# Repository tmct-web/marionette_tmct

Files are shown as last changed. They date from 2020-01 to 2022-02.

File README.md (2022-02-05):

# marionette_tmct

## What is "Marionette" ?
Marionettes are so-called puppets.We created this to remotely control multiple remote devices via USB from a single PC.

This system contains two Arduino Leonardo, the controlling side (master side) and the controlled side (slave side).

For example, the USB port connected to the controlling side (master side) is USB-COM, and the USB port connected to the controlled side (slave side) is an HID keyboard (= the slave side looks like a normal HID keyboard). Then you can control the slave keyboard with USB-COM on the master.

マリオネッテと書いてマリオネットと読みます。マリオネットはいわゆる操り人形のことですね。
もともと1台のパソコンからUSB経由で複数の相手機器を遠隔コントロールするために作ったものです。

このシステムは、制御する側（マスタ側）・制御される側（スレーブ側）の2つ分のArduino Leonardoが入っている、ちょっと変わったハードウェアになっています。

たとえば制御する側（マスタ側）に繋がるUSBポートはUSB-COM、制御される側（スレーブ側）につながるUSBポートはHIDキーボード（＝スレーブ側は普通のHIDキーボードに見える）、という構成にすると、マスタ側のUSB-COMでスレーブ側をキーボード制御する、なんてことができます。

Example

## Hardware specifications
Marionette has two circuits of Arduino Leonardo.

The two circuits are called a master (MASTER) and a slave (SLAVE), respectively, and can be operated completely differently by different programs. The hardware block diagram is shown below.

MarionetteはArduino Leonardoの2枚分の回路が実装されています。

2枚分の回路はそれぞれマスタ(MASTER)とスレーブ(SLAVE)と呼び、各々別のプログラムでまったく別の動作をさせることができます。ハードウェアのブロック図を以下に示します。

Hardware block diagram

See our [homepage](https://ss1.xrea.com/tmct.s1009.xrea.com/work/td-ja-7e2g01.html) for more information.(* Japanese only)

詳細は [ホームページ](https://ss1.xrea.com/tmct.s1009.xrea.com/work/td-ja-7e2g01.html) を参照してください。

## Recommended projects
We recommend this project. Compatibility with Marionette is outstanding.

Marionetteで使用すると、良い結果が得られるでしょう。

[NicoHood/HID](https://github.com/NicoHood/HID)

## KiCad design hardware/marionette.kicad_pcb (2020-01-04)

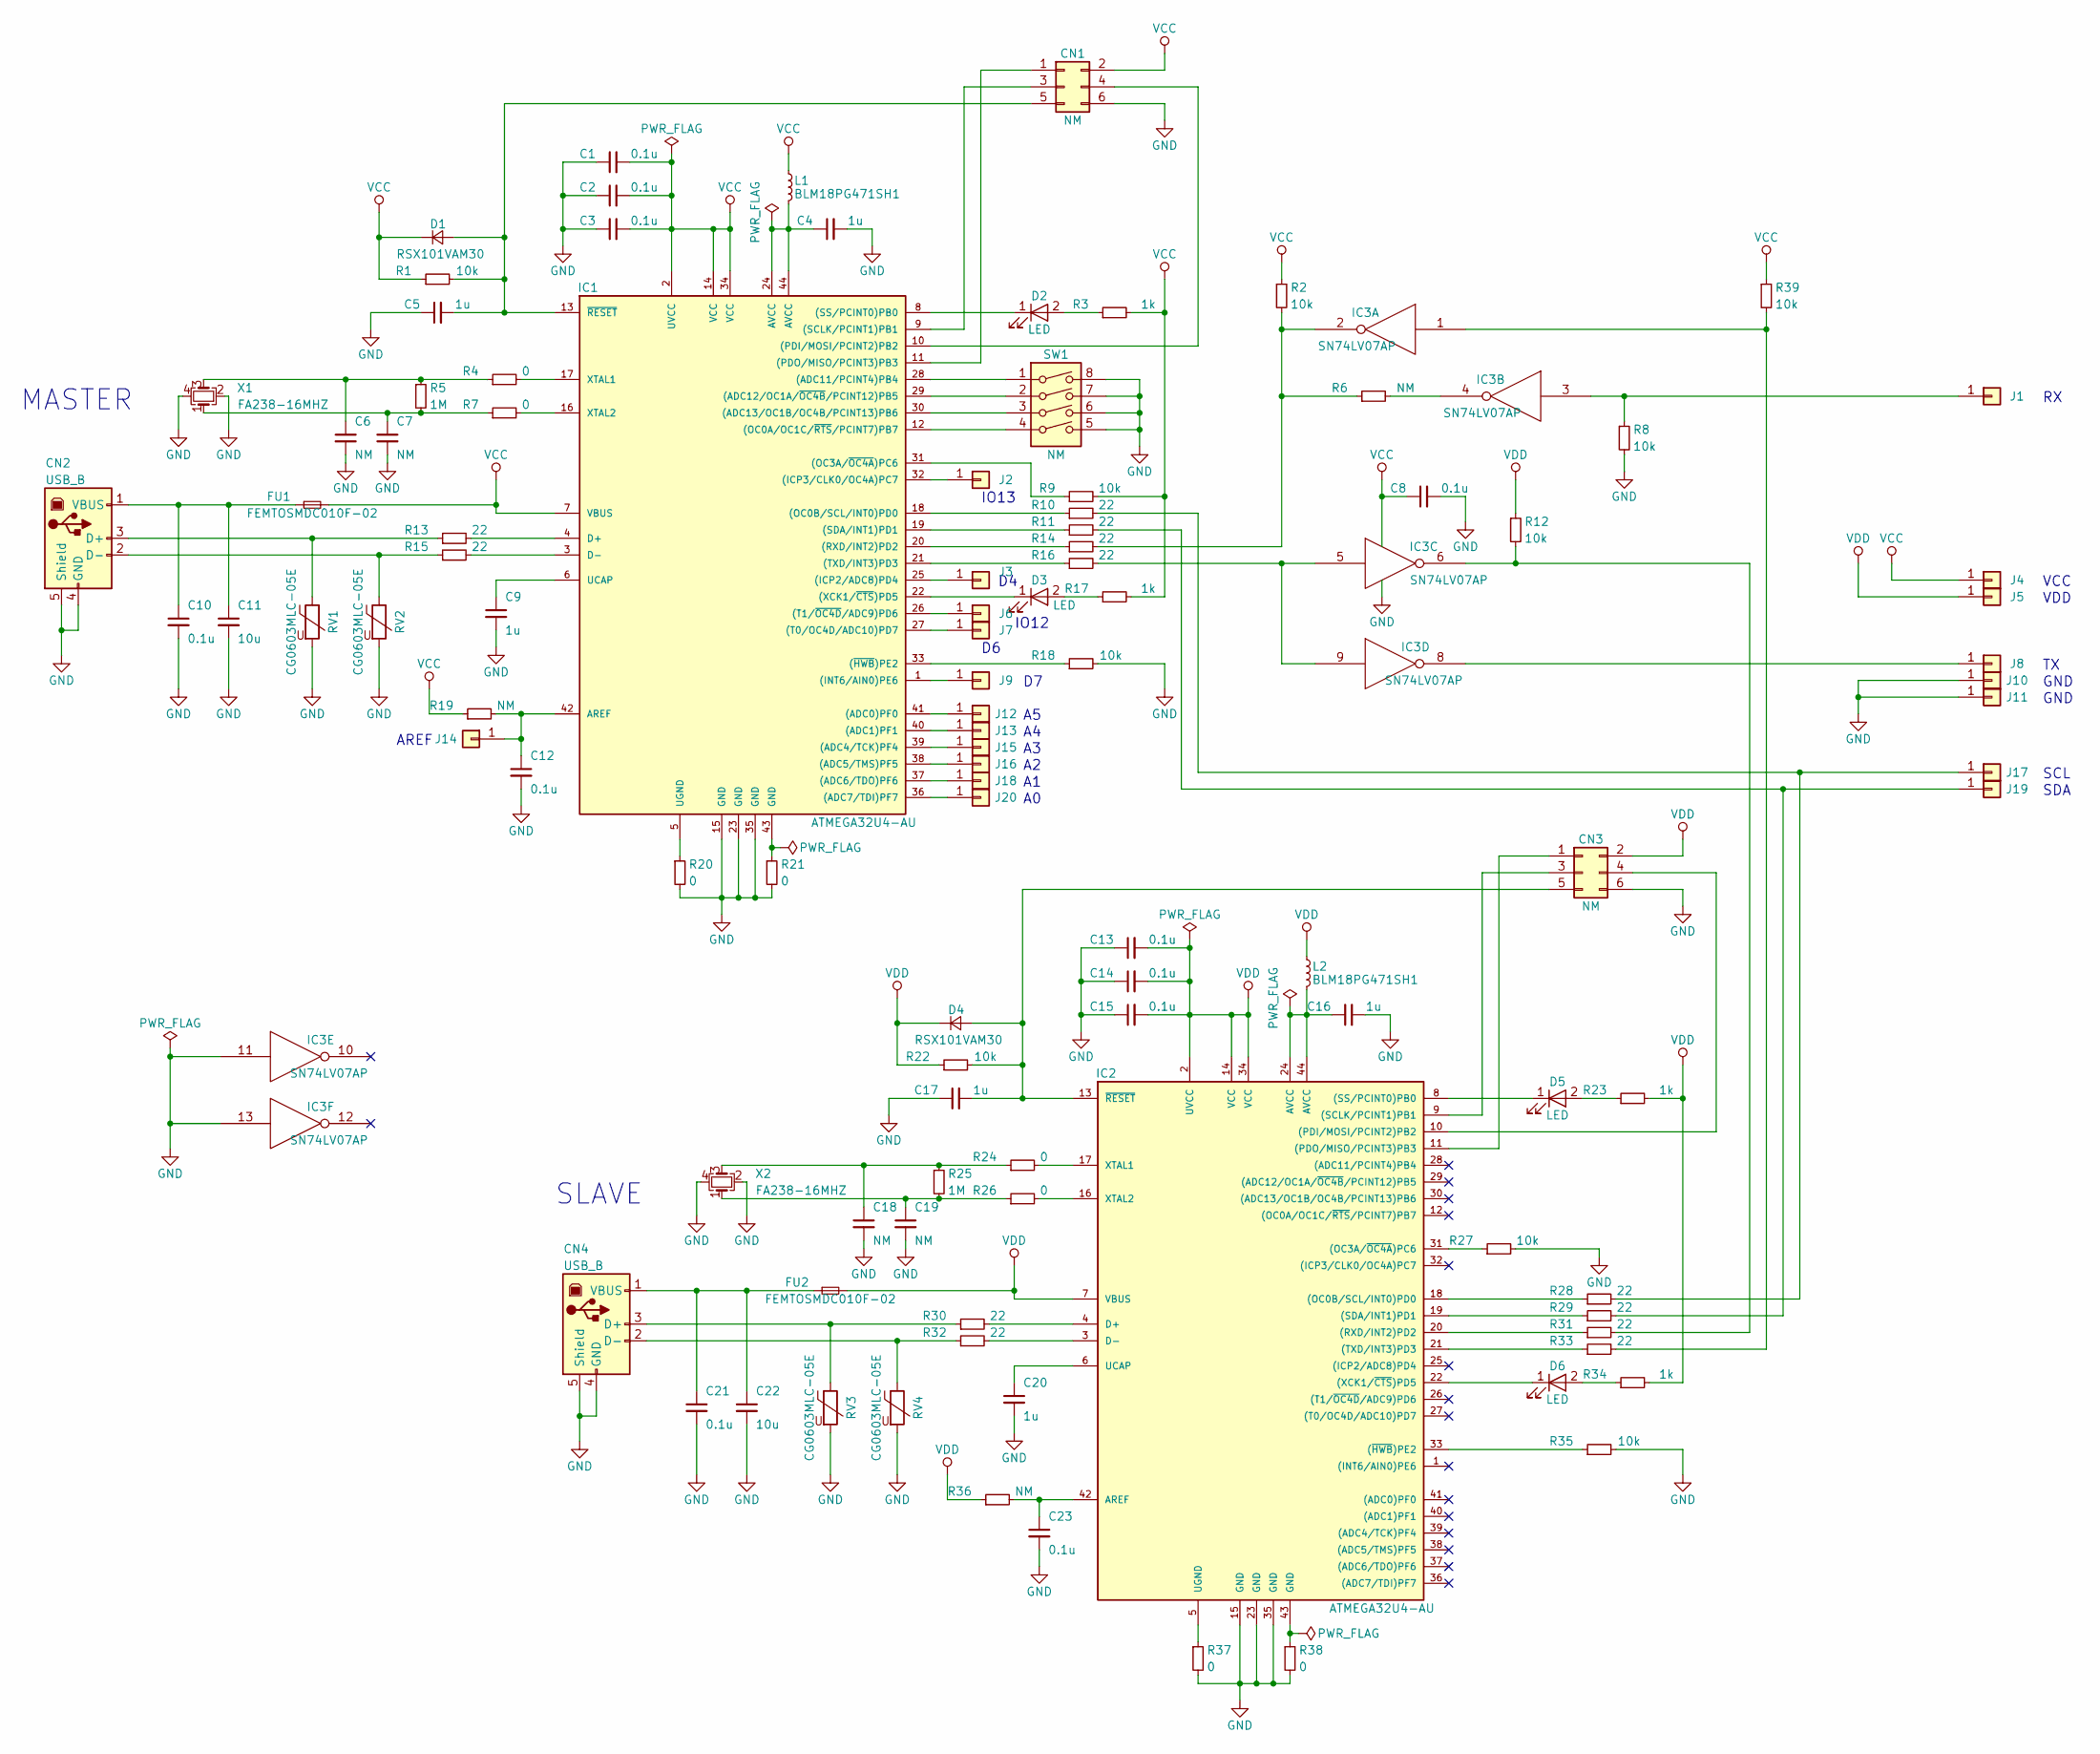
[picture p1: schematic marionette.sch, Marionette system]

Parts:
C1, C2, C3, C8, C10, C12, C13, C14, C15, C21, C23: 0.1u; C_0603
C4, C5, C9, C16, C17, C20: 1u; C_0603
C6, C7, C18, C19: NM; C_0603
C11, C22: 10u; C_0805
CN1, CN3: NM; Pin_Header_Straight_2x03_Pitch2.54mm
CN2, CN4: USB_B
D1, D4: RSX101VAM30; D_TUMD2
D2, D3, D5, D6: LED; LED_0603
FU1, FU2: FEMTOSMDC010F-02; C_0603
IC1, IC2: ATMEGA32U4-AU; TQFP-44_10x10mm_Pitch0.8mm
IC3: SN74LV07AP; TSSOP-14_4.4x5mm_Pitch0.65mm
J1, J2, J3, J4, J5, J6, J7, J8, J9, J10, J11, J12, J13, J14, J15, J16, J17, J18, J19, J20: Conn_01x01; Measurement_Point_Round-TH_Small
L1, L2: BLM18PG471SH1; L_0603
R1, R2, R8, R9, R12, R18, R22, R27, R35, R39: 10k; R_0603
R3, R17, R23, R34: 1k; R_0603
R4, R7, R20, R21, R24, R26, R37, R38: 0; R_0603
R5, R25: 1M; R_0603
R6, R19, R36: NM; R_0603
R10, R11, R13, R14, R15, R16, R28, R29, R30, R31, R32, R33: 22; R_0603
RV1, RV2, RV3, RV4: CG0603MLC-05E; C_0603
SW1: NM; DIP-8_W7.62mm_LongPads
X1, X2: FA238-16MHZ; Crystal_SMD_3225-4pin_3.2x2.5mm

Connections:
GND: C1.1, C2.1, C3.1, C4.2, C5.1, C6.2, C7.2, C8.2, C9.2, C10.2, C11.2, C12.2, C13.1, C14.1, C15.1, C16.2, C17.1, C18.2, C19.2, C20.2, C21.2, C22.2, C23.2, CN1.6, CN2.4 (GND), CN2.5 (Shield), CN3.6, CN4.4 (GND), CN4.5 (Shield), IC1.15 (GND), IC1.23 (GND), IC1.35 (GND), IC2.15 (GND), IC2.23 (GND), IC2.35 (GND), IC3.7 (GND), IC3.11, IC3.13, J10.1, J11.1, R8.2, R18.2, R20.2, R21.2, R27.2, R35.2, R37.2, R38.2, RV1.2, RV2.2, RV3.2, RV4.2, SW1.5, SW1.6, SW1.7, SW1.8, X1.2, X1.4, X2.2, X2.4
unnamed: C4.1, IC1.24 (AVCC), IC1.44 (AVCC), L1.2
unnamed: C5.2, CN1.5, D1.2 (A), IC1.13 (~RESET~), R1.2
unnamed: C6.1, R4.1, R5.1, X1.3
unnamed: C7.1, R5.2, R7.1, X1.1
unnamed: C9.1, IC1.6 (UCAP)
unnamed: C10.1, C11.1, CN2.1 (VBUS), FU1.1
unnamed: C12.1, IC1.42 (AREF), J14.1, R19.2
unnamed: C16.1, IC2.24 (AVCC), IC2.44 (AVCC), L2.2
unnamed: C17.2, CN3.5, D4.2 (A), IC2.13 (~RESET~), R22.2
unnamed: C18.1, R24.1, R25.1, X2.3
unnamed: C19.1, R25.2, R26.1, X2.1
unnamed: C20.1, IC2.6 (UCAP)
unnamed: C21.1, C22.1, CN4.1 (VBUS), FU2.1
unnamed: C23.1, IC2.42 (AREF), R36.2
unnamed: CN1.1, IC1.11 ((PDO/MISO/PCINT3)PB3)
unnamed: CN1.3, IC1.9 ((SCLK/PCINT1)PB1)
unnamed: CN1.4, IC1.10 ((PDI/MOSI/PCINT2)PB2)
unnamed: CN2.2 (D-), R15.1, RV2.1
unnamed: CN2.3 (D+), R13.1, RV1.1
unnamed: CN3.1, IC2.11 ((PDO/MISO/PCINT3)PB3)
unnamed: CN3.3, IC2.9 ((SCLK/PCINT1)PB1)
unnamed: CN3.4, IC2.10 ((PDI/MOSI/PCINT2)PB2)
unnamed: CN4.2 (D-), R32.1, RV4.1
unnamed: CN4.3 (D+), R30.1, RV3.1
unnamed: D2.1 (K), IC1.8 ((SS/PCINT0)PB0)
unnamed: D2.2 (A), R3.1
unnamed: D3.1 (K), IC1.22 ((XCK1/~CTS~)PD5)
unnamed: D3.2 (A), R17.1
unnamed: D5.1 (K), IC2.8 ((SS/PCINT0)PB0)
unnamed: D5.2 (A), R23.1
unnamed: D6.1 (K), IC2.22 ((XCK1/~CTS~)PD5)
unnamed: D6.2 (A), R34.1
unnamed: IC1.1 ((INT6/AIN0)PE6), J9.1
unnamed: IC1.3 (D-), R15.2
unnamed: IC1.4 (D+), R13.2
unnamed: IC1.5 (UGND), R20.1
unnamed: IC1.12 ((OC0A/OC1C/~RTS~/PCINT7)PB7), SW1.4
unnamed: IC1.16 (XTAL2), R7.2
unnamed: IC1.17 (XTAL1), R4.2
unnamed: IC1.18 ((OC0B/SCL/INT0)PD0), R10.1
unnamed: IC1.19 ((SDA/INT1)PD1), R11.1
unnamed: IC1.20 ((RXD/INT2)PD2), R14.1
unnamed: IC1.21 ((TXD/INT3)PD3), R16.1
unnamed: IC1.25 ((ICP2/ADC8)PD4), J3.1
unnamed: IC1.26 ((T1/~OC4D~/ADC9)PD6), J6.1
unnamed: IC1.27 ((T0/OC4D/ADC10)PD7), J7.1
unnamed: IC1.28 ((ADC11/PCINT4)PB4), SW1.1
unnamed: IC1.29 ((ADC12/OC1A/~OC4B~/PCINT12)PB5), SW1.2
unnamed: IC1.30 ((ADC13/OC1B/OC4B/PCINT13)PB6), SW1.3
unnamed: IC1.31 ((OC3A/~OC4A~)PC6), R9.1
unnamed: IC1.32 ((ICP3/CLK0/OC4A)PC7), J2.1
unnamed: IC1.33 ((~HWB~)PE2), R18.1
unnamed: IC1.36 ((ADC7/TDI)PF7), J20.1
unnamed: IC1.37 ((ADC6/TDO)PF6), J18.1
unnamed: IC1.38 ((ADC5/TMS)PF5), J16.1
unnamed: IC1.39 ((ADC4/TCK)PF4), J15.1
unnamed: IC1.40 ((ADC1)PF1), J13.1
unnamed: IC1.41 ((ADC0)PF0), J12.1
unnamed: IC1.43 (GND), R21.1
unnamed: IC2.3 (D-), R32.2
unnamed: IC2.4 (D+), R30.2
unnamed: IC2.5 (UGND), R37.1
unnamed: IC2.16 (XTAL2), R26.2
unnamed: IC2.17 (XTAL1), R24.2
unnamed: IC2.18 ((OC0B/SCL/INT0)PD0), R28.1
unnamed: IC2.19 ((SDA/INT1)PD1), R29.1
unnamed: IC2.20 ((RXD/INT2)PD2), R31.1
unnamed: IC2.21 ((TXD/INT3)PD3), R33.1
unnamed: IC2.31 ((OC3A/~OC4A~)PC6), R27.1
unnamed: IC2.33 ((~HWB~)PE2), R35.1
unnamed: IC2.43 (GND), R38.1
unnamed: IC3.1, R33.2, R39.2
unnamed: IC3.2, R2.2, R6.1, R14.2
unnamed: IC3.3, J1.1, R8.1
unnamed: IC3.4, R6.2
unnamed: IC3.5, IC3.9, R16.2
unnamed: IC3.6, R12.2, R31.2
unnamed: IC3.8, J8.1
unnamed: J17.1, R10.2, R28.2
unnamed: J19.1, R11.2, R29.2
VCC: C1.2, C2.2, C3.2, C8.1, CN1.2, D1.1 (K), FU1.2, IC1.2 (UVCC), IC1.7 (VBUS), IC1.14 (VCC), IC1.34 (VCC), IC3.14 (VCC), J4.1, L1.1, R1.1, R2.1, R3.2, R9.2, R17.2, R19.1, R39.1
VDD: C13.2, C14.2, C15.2, CN3.2, D4.1 (K), FU2.2, IC2.2 (UVCC), IC2.7 (VBUS), IC2.14 (VCC), IC2.34 (VCC), J5.1, L2.1, R12.1, R22.1, R23.2, R34.2, R36.1

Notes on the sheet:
MASTER
SLAVE
AREF
VCC
VDD
GND
SCL
SDA
IO13
IO12

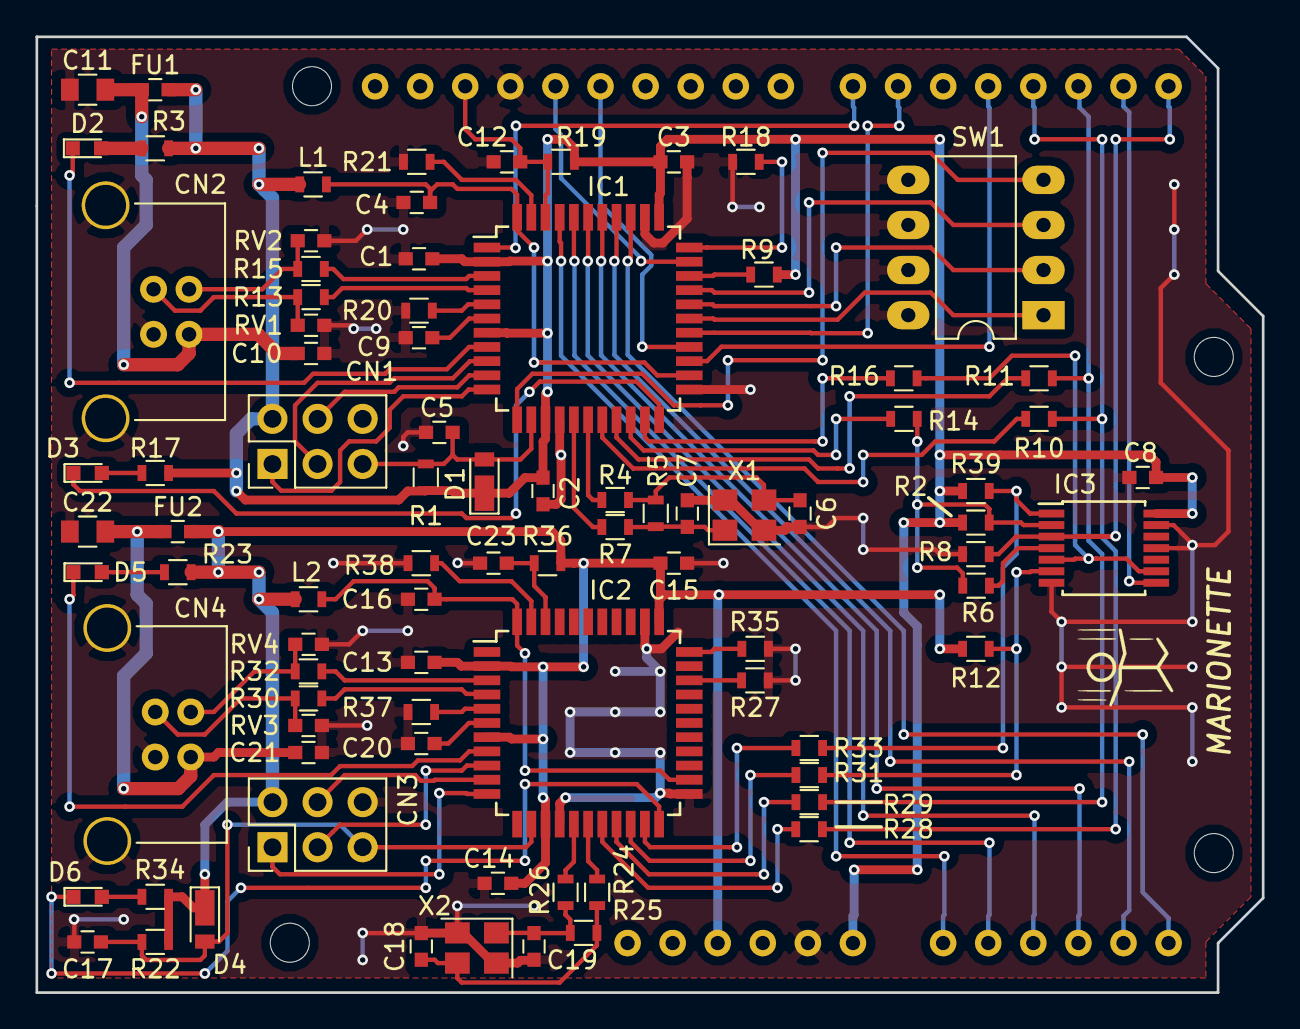
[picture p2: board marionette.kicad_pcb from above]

Board: 2 copper layers, 69.1 x 53.8 mm, 110 parts (0 on the bottom side), 83 nets.

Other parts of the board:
REF100, REF101, REF102, REF103: MountingHole_2.2mm_M2

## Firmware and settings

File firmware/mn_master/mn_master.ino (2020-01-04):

/*---------------------------------------------------------------------------*/
//  MARIONETTE system : MASTER device firmware
//
//  Filename      : mn_master.ino
//  Target system : MARIONETTE system
//  Target device : ATMEGA32U4
//
//  [Revision history]
//  Date        Version   Author            Detail
//  -------------------------------------------------------------------------
//  2018.07.15  1.00      TMC               Initial release.
/*---------------------------------------------------------------------------*/
#define receiveBufferLength 17
#define terminationCode     '\r'
#define promptCode          '$'
#define resultCode          '#'

/*---------------------------------------------------------------------------*/
//  Function prototype definition
/*---------------------------------------------------------------------------*/
void setup();
void loop();
void commandDigitalDirection();
void commandDigitalIn();
void commandDigitalOut();
void commandAnalogIn();
void commandSendToSlave();


/*---------------------------------------------------------------------------*/
//  CONST definition
/*---------------------------------------------------------------------------*/
const char messageFirmwareName[] = "MARIONETTE system firmware";
const char messageFirmwareVersion[] = "1.00";

const int portMasterDetect = 5;
const int portDipSw0 = 8;
const int portDipSw1 = 9;
const int portDipSw2 = 10;
const int portDipSw3 = 11;
const int portD3_PD0 = 3;
const int portD2_PD1 = 2;
const int portD0_PD2 = 0;
const int portD1_PD3 = 1;
const int portD4_PD4 = 4;
const int portD12_PD6 = 12;
const int portD6_PD7 = 6;
const int portD13_PC7 = 13;
const int portD7_PE6 = 7;
const int portA5_PF0 = 23;
const int portA4_PF1 = 22;
const int portA3_PF4 = 21;
const int portA2_PF5 = 20;
const int portA1_PF6 = 19;
const int portA0_PF7 = 18;


/*---------------------------------------------------------------------------*/
//  Global variable definition
/*---------------------------------------------------------------------------*/
unsigned char receiveBuffer[receiveBufferLength];
char receiveBytes;
char boardID;


/*---------------------------------------------------------------------------*/
//  Setup function
/*---------------------------------------------------------------------------*/
//  [Arguments]
//    None
//  [Returns]
//    None
//  [Note]
//    Arduino setup function
/*---------------------------------------------------------------------------*/
void setup() {
  
  /*-------------------------------------------------------------------------*/
  //  Port initialization
  /*-------------------------------------------------------------------------*/
  analogReference(DEFAULT);
  pinMode(portMasterDetect, INPUT_PULLUP);
  pinMode(portDipSw0, INPUT_PULLUP);
  pinMode(portDipSw1, INPUT_PULLUP);
  pinMode(portDipSw2, INPUT_PULLUP);
  pinMode(portDipSw3, INPUT_PULLUP);
  pinMode(portD3_PD0, INPUT_PULLUP);
  pinMode(portD2_PD1, INPUT_PULLUP);
  pinMode(portD0_PD2, INPUT_PULLUP);
  pinMode(portD1_PD3, INPUT_PULLUP);
  pinMode(portD4_PD4, INPUT_PULLUP);
  pinMode(portD12_PD6, INPUT_PULLUP);
  pinMode(portD6_PD7, INPUT_PULLUP);
  pinMode(portD13_PC7, INPUT_PULLUP);
  pinMode(portD7_PE6, INPUT_PULLUP);
  pinMode(portA5_PF0, INPUT_PULLUP);
  pinMode(portA4_PF1, INPUT_PULLUP);
  pinMode(portA3_PF4, INPUT_PULLUP);
  pinMode(portA2_PF5, INPUT_PULLUP);
  pinMode(portA1_PF6, INPUT_PULLUP);
  pinMode(portA0_PF7, INPUT_PULLUP);
  TXLED0;
  RXLED0;
  
  /*-------------------------------------------------------------------------*/
  //  Master and Slave detection
  /*-------------------------------------------------------------------------*/
  if (digitalRead(portMasterDetect) != HIGH) {
    /*----- Wrong firmware -----*/
    while (1) {
      // Dead loop
      TXLED1;
      RXLED0;
      delay(300);
      TXLED0;
      RXLED1;
      delay(300);    
    }
  }
  else
  {
    /*----- Right firmware -----*/
    TXLED1;
    RXLED1;
    delay(3000);
    TXLED0;
    RXLED0;
  }

  /*-------------------------------------------------------------------------*/
  //  Board ID Recognition
  /*-------------------------------------------------------------------------*/
  if (digitalRead(portDipSw3) == LOW) boardID = 8; else boardID = 0;
  if (digitalRead(portDipSw2) == LOW) boardID |= 4;
  if (digitalRead(portDipSw1) == LOW) boardID |= 2;
  if (digitalRead(portDipSw0) == LOW) boardID |= 1;
  
  /*-------------------------------------------------------------------------*/
  //  Serial initialization
  /*-------------------------------------------------------------------------*/
  Serial.begin(9600, SERIAL_8N1);   // for Host communication(USB-CDC)
  Serial1.begin(9600, SERIAL_8N1);  // for Slave communication
  Serial1.setTimeout(500);

  /*-------------------------------------------------------------------------*/
  //  Display initial message
  /*-------------------------------------------------------------------------*/
  Serial.println("");
  Serial.print("== ");
  Serial.print(messageFirmwareName);
  Serial.println(" ==");
  Serial.print("Version ");
  Serial.print(messageFirmwareVersion);
  Serial.print("   build "); Serial.print(__DATE__);
  Serial.print(" "); Serial.println(__TIME__);  
  
}


/*---------------------------------------------------------------------------*/
//  Loop function
/*---------------------------------------------------------------------------*/
//  [Arguments]
//    None
//  [Returns]
//    None
//  [Note]
//    Arduino loop function
/*---------------------------------------------------------------------------*/
void loop() {

  unsigned char i;
  unsigned char terminated;
  int receiveCode;

  // d03ip   Direction
  // i03     Input
  // o03h    Output
  // a00     Analog input
  // s      Send slave

  /*-------------------------------------------------------------------------*/
  //  Monitor loop
  /*-------------------------------------------------------------------------*/
  /*----- Variable initialization -----*/
  receiveBytes = 0;
  terminated = 0;
  receiveCode = 0;
  for (i = 0; i < receiveBufferLength; i++) receiveBuffer[i] = '\0';

  /*----- Loop until receiving the termination code -----*/
  Serial.print(boardID, HEX);
  Serial.print(promptCode);
  while (terminated == 0) {
    if (Serial.available() != 0) {
      receiveCode = Serial.read();
      if (receiveCode == terminationCode) {
        Serial.println("");
        terminated = 1;
        break;
      }
      receiveBuffer[receiveBytes] = (unsigned char)receiveCode;
      if (receiveBytes < receiveBufferLength - 2) receiveBytes++;
      if (((0x00 <= receiveCode) && (receiveCode <= 0x1f)) || (receiveCode == 0x7f)) {
        Serial.print('^');
        Serial.print(receiveCode, DEC);
      }
      else
      {
        Serial.write(receiveCode);
      }
    }
  }

  /*----- Branch to command -----*/
  switch (receiveBuffer[0]) {
    case 'D':
    case 'd':
      commandDigitalDirection();
      break;
    case 'I':
    case 'i':
      commandDigitalIn();
      break;
    case 'O':
    case 'o':
      commandDigitalOut();
      break;
    case 'A':
    case 'a':
      commandAnalogIn();
      break;
    case 'S':
    case 's':
      commandSendToSlave();
      break;
    default:
      break;
  }
  Serial.print("Terminated. length = ");
  Serial.println(receiveBytes, DEC);
  for (i = 0; i < receiveBufferLength; i++) {
    Serial.println(receiveBuffer[i], HEX);
  }
  Serial.println("");
  
}


/*---------------------------------------------------------------------------*/
//  Processing of digital port direction setting command
/*---------------------------------------------------------------------------*/
//  [Arguments]
//    None
//  [Returns]
//    None
//  [Note]
//    None
/*---------------------------------------------------------------------------*/
void commandDigitalDirection() {

  char portMode;
  char portNumberChar[3];
  char portNumber;

  /*-------------------------------------------------------------------------*/
  //  Interpret buffer contents
  /*-------------------------------------------------------------------------*/
  /*----- Direction -----*/
  if ((receiveBuffer[3] == 'o') || (receiveBuffer[3] == 'O')) {
    portMode = OUTPUT;
  }
  else {
    if ((receiveBuffer[4] == 'p') || (receiveBuffer[3] == 'P')) portMode = INPUT_PULLUP; else portMode = INPUT;
  }

  /*----- Port number -----*/
  portNumberChar[0] = receiveBuffer[1];
  portNumberChar[1] = receiveBuffer[2];
  portNumberChar[2] = '\0';
  portNumber = atoi(portNumberChar);

  /*-------------------------------------------------------------------------*/
  //  Switch port mode
  /*-------------------------------------------------------------------------*/
  switch (portNumber) {
    case 2:
      pinMode(portD2_PD1, portMode);
      break;
    case 3:
      pinMode(portD3_PD0, portMode);
      break;
    case 4:
      pinMode(portD4_PD4, portMode);
      break;
    case 6:
      pinMode(portD6_PD7, portMode);
      break;
    case 7:
      pinMode(portD7_PE6, portMode);
      break;
    case 12:
      pinMode(portD12_PD6, portMode);
      break;
    case 13:
      pinMode(portD13_PC7, portMode);
      break;
    case 18:
      pinMode(portA0_PF7, portMode);
      break;
    case 19:
      pinMode(portA1_PF6, portMode);
      break;
    case 20:
      pinMode(portA2_PF5, portMode);
      break;
    case 21:
      pinMode(portA3_PF4, portMode);
      break;
    case 22:
      pinMode(portA4_PF1, portMode);
      break;
    case 23:
      pinMode(portA5_PF0, portMode);
      break;
    default:
      break;
  }

  /*-------------------------------------------------------------------------*/
  //  Display result
  /*-------------------------------------------------------------------------*/
  Serial.print(resultCode);
  Serial.print(portNumber, DEC);
  Serial.print(",");
  Serial.println(portMode, DEC);
  
}


/*---------------------------------------------------------------------------*/
//  Processing digital port input command
/*---------------------------------------------------------------------------*/
//  [Arguments]
//    None
//  [Returns]
//    None
//  [Note]
//    None
/*---------------------------------------------------------------------------*/
void commandDigitalIn() {

  int readResult;
  char portNumberChar[3];
  char portNumber;

  /*-------------------------------------------------------------------------*/
  //  Interpret buffer contents
  /*-------------------------------------------------------------------------*/
  /*----- Port number -----*/
  portNumberChar[0] = receiveBuffer[1];
  portNumberChar[1] = receiveBuffer[2];
  portNumberChar[2] = '\0';
  portNumber = atoi(portNumberChar);

  /*-------------------------------------------------------------------------*/
  //  Digital read
  /*-------------------------------------------------------------------------*/
  switch (portNumber) {
    case 2:
      readResult = digitalRead(portD2_PD1);
      break;
    case 3:
      readResult = digitalRead(portD3_PD0);
      break;
    case 4:
      readResult = digitalRead(portD4_PD4);
      break;
    case 6:
      readResult = digitalRead(portD6_PD7);
      break;
    case 7:
      readResult = digitalRead(portD7_PE6);
      break;
    case 12:
      readResult = digitalRead(portD12_PD6);
      break;
    case 13:
      readResult = digitalRead(portD13_PC7);
      break;
    case 18:
      readResult = digitalRead(portA0_PF7);
      break;
    case 19:
      readResult = digitalRead(portA1_PF6);
      break;
    case 20:
      readResult = digitalRead(portA2_PF5);
      break;
    case 21:
      readResult = digitalRead(portA3_PF4);
      break;
    case 22:
      readResult = digitalRead(portA4_PF1);
      break;
    case 23:
      readResult = digitalRead(portA5_PF0);
      break;
    default:
      break;
  }

  /*-------------------------------------------------------------------------*/
  //  Display result
  /*-------------------------------------------------------------------------*/
  Serial.print(resultCode);
  Serial.print(portNumber, DEC);
  Serial.print(",");
  if (readResult == HIGH) Serial.println("H"); else Serial.println("L");
  
}


/*---------------------------------------------------------------------------*/
//  Processing digital port output command
/*---------------------------------------------------------------------------*/
//  [Arguments]
//    None
//  [Returns]
//    None
//  [Note]
//    None
/*---------------------------------------------------------------------------*/
void commandDigitalOut() {

  int writeValue;
  char portNumberChar[3];
  char portNumber;

  /*-------------------------------------------------------------------------*/
  //  Interpret buffer contents
  /*-------------------------------------------------------------------------*/
  /*----- Port number -----*/
  portNumberChar[0] = receiveBuffer[1];
  portNumberChar[1] = receiveBuffer[2];
  portNumberChar[2] = '\0';
  portNumber = atoi(portNumberChar);
  /*----- Port logic -----*/
  if ((receiveBuffer[3] == 'h') || (receiveBuffer[3] == 'H')) writeValue = HIGH; else writeValue = LOW;

  /*-------------------------------------------------------------------------*/
  //  Digital write
  /*-------------------------------------------------------------------------*/
  switch (portNumber) {
    case 2:
      digitalWrite(portD2_PD1, writeValue);
      break;
    case 3:
      digitalWrite(portD3_PD0, writeValue);
      break;
    case 4:
      digitalWrite(portD4_PD4, writeValue);
      break;
    case 6:
      digitalWrite(portD6_PD7, writeValue);
      break;
    case 7:
      digitalWrite(portD7_PE6, writeValue);
      break;
    case 12:
      digitalWrite(portD12_PD6, writeValue);
      break;
    case 13:
      digitalWrite(portD13_PC7, writeValue);
      break;
    case 18:
      digitalWrite(portA0_PF7, writeValue);
      break;
    case 19:
      digitalWrite(portA1_PF6, writeValue);
      break;
    case 20:
      digitalWrite(portA2_PF5, writeValue);
      break;
    case 21:
      digitalWrite(portA3_PF4, writeValue);
      break;
    case 22:
      digitalWrite(portA4_PF1, writeValue);
      break;
    case 23:
      digitalWrite(portA5_PF0, writeValue);
      break;
    default:
      break;
  }

  /*-------------------------------------------------------------------------*/
  //  Display result
  /*-------------------------------------------------------------------------*/
  Serial.print(resultCode);
  Serial.print(portNumber, DEC);
  Serial.print(",");
  Serial.println(writeValue, DEC);
  
}


/*---------------------------------------------------------------------------*/
//  Processing analog port input command
/*---------------------------------------------------------------------------*/
//  [Arguments]
//    None
//  [Returns]
//    None
//  [Note]
//    None
/*---------------------------------------------------------------------------*/
void commandAnalogIn() {

  int readResult;
  char portNumberChar[3];
  char portNumber;

  /*-------------------------------------------------------------------------*/
  //  Interpret buffer contents
  /*-------------------------------------------------------------------------*/
  /*----- Port number -----*/
  portNumberChar[0] = receiveBuffer[1];
  portNumberChar[1] = receiveBuffer[2];
  portNumberChar[2] = '\0';
  portNumber = atoi(portNumberChar);

  /*-------------------------------------------------------------------------*/
  //  Analog read
  /*-------------------------------------------------------------------------*/
  switch (portNumber) {
    case 0:
      readResult = analogRead(0);
      break;
    case 1:
      readResult = analogRead(1);
      break;
    case 2:
      readResult = analogRead(2);
      break;
    case 3:
      readResult = analogRead(3);
      break;
    case 4:
      readResult = analogRead(4);
      break;
    case 5:
      readResult = analogRead(5);
      break;
    case 6:
      readResult = analogRead(6);
      break;
    case 7:
      readResult = analogRead(7);
      break;
    case 8:
      readResult = analogRead(8);
      break;
    case 9:
      readResult = analogRead(9);
      break;
    case 10:
      readResult = analogRead(10);
      break;
    case 11:
      readResult = analogRead(11);
      break;
    default:
      break;
  }

  /*-------------------------------------------------------------------------*/
  //  Display result
  /*-------------------------------------------------------------------------*/
  Serial.print(resultCode);
  Serial.print(portNumber, DEC);
  Serial.print(",");
  Serial.println(readResult, DEC);
  
}


/*---------------------------------------------------------------------------*/
//  Processing of slave device transmission command
/*---------------------------------------------------------------------------*/
//  [Arguments]
//    None
//  [Returns]
//    None
//  [Note]
//    None
/*---------------------------------------------------------------------------*/
void commandSendToSlave() {

  int i;

  Serial.print(resultCode);
  
  for (i = 1; i <= receiveBufferLength - 1; i++) {
    if (receiveBuffer[i] != '\0') {
      Serial1.write(receiveBuffer[i]);
      Serial.print('^');
      Serial.print(receiveBuffer[i], DEC);
    }
    else break;
  }
  Serial.println("");
  
}
